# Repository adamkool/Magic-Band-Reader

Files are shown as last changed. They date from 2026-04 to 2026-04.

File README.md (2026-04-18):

# 🪄 Magic Band

Last Halloween I came across [this video](https://www.youtube.com/watch?v=f09JSgdGhIk) in a Facebook group with a replica of the Haunted Mansion Magic Band reader for the Lightning Lane at Disney World. Fortunately, the creator made the 3D print files available, but excluded the electronics that make it come to life. The electronics were excluded due to a complex, multi-unit custom implementation. Since my kids love going to Disney, I wanted to build one for them. There's also been growing interest in a standalone solution — so this is for everyone who would like to build their own.

mb-reader-static

## Overview

The Magic Band reader is powered by a Raspberry Pi Zero 2w. When powered on, the Raspberry Pi will automatically run the program. In the idle state, the LED lights will circle the reader. When an RFID card is presented to the reader, an LED animation is triggered along with a "chime" sound. If the audio is replaced with something longer, there is an option to tap the RFID card again which will stop the audio. The lights will briefly turn the lights red to acknowledge the tap.

The current implementation of this Magic Band reader is compatible with virtually any 13.56MHz RFID device.

## Bill of Materials

- **[Raspberry Pi Zero 2W](https://www.digikey.ca/en/products/detail/raspberry-pi/SC0721/24627135)** — The brains of the operation
- **[RC522 Mini RFID Reader](https://www.aliexpress.com/item/1005006907801802.html)** — SPI-connected tag scanning
- **[MAX98357A I2S Amplifier](https://www.digikey.ca/en/products/detail/adafruit-industries-llc/3006/6058477)** — digital audio output
- **[Adafruit 3351 Speaker](https://www.digikey.ca/en/products/detail/adafruit-industries-llc/3351/6612456)** - plays audio, does not require power source
- **[BTF-Lighting 1m 144 Light LED Strip](https://www.amazon.ca/dp/B0F5WQLMK7?ref_=ppx_hzsearch_conn_dt_b_fed_asin_title_6&th=1)** — LED lights
- **[BTF-Lighting 5V 6A PSU](https://www.amazon.ca/dp/B0FNWDR7TT?ref_=ppx_hzsearch_conn_dt_b_fed_asin_title_2&th=1)** — powers LED lights
- **[Micro SD card 32-64gb](https://www.amazon.ca/SanDisk-Extreme-microSDXC-Memory-Adapter/dp/B09X7C7LL1?th=1)** - SD card for Raspberry Pi OS and audio files
- **[Dupont cables](https://www.amazon.ca/RGBZONE-Multicolored-Breadboard-Arduino-Raspberry/dp/B08TWSV2DY?th=1)** - Various cables to connect everything
- **[WAGO 221 Lever Nuts](https://www.homedepot.ca/product/wago-lever-nuts-3-conductor-compact-splicing-connectors-12-24awg-10-pack-/1001877147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)** - Easily connect wires together without having to solder them

All of the materials needed to make the housing for the electronics can be found in the [Makerworld file](https://makerworld.com/en/models/1998101-disney-haunted-mansion-inspired-magicband-reader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)

## Features

- RFID tag detection triggers LED lights and audio file
- Programming of individual RFID tags is not needed. There is no limit on how many tags you can use.
- Replaceable audio with stop functionality
- Animation timing is easily configurable

## Tech Stack

- Python (Pi-side RFID + LED lights + audio logic)
- I2S audio, SPI (RFID)

## Supporting files

- [Model of the Magic Band reader housing](https://makerworld.com/en/models/1998101-disney-haunted-mansion-inspired-magicband-reader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)
- [Internal control panel (Print ready)](https://github.com/adamkool/magic-band-reader/blob/0c3ac6cd2602aba7beed5e0e5c9bfb62491abfb1/Magic%20Band%20Control%20Board.stl)
- [Internal control panel Fusion file (Excludes WAGO terminal)](https://github.com/adamkool/magic-band-reader/blob/0c3ac6cd2602aba7beed5e0e5c9bfb62491abfb1/Magic%20Band%20Control%20Board.f3d)
- [WAGO Terminal](https://makerworld.com/en/models/936345-wago-221-awg-24-12-connector-modular-mount-for-3x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)

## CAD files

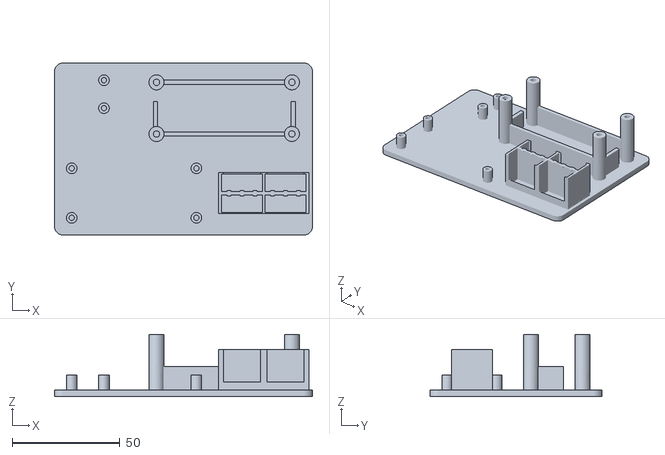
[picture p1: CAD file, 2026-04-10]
Magic Band Control Board.stl
120.0 x 80.0 x 29.0

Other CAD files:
Magic Band Control Board.f3d

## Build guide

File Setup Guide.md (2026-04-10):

# Magic Band RFID Audio Player — Complete Setup Guide

A beginner-friendly guide to building an RFID-triggered audio player with LED animations using a Raspberry Pi Zero 2W. When you tap an RFID tag, the LEDs animate and a chime plays — just like a Disney Magic Band.

---

## What You'll Need

### Hardware
| Item | Notes |
|---|---|
| Raspberry Pi Zero 2W | The main brain of the project |
| MicroSD card | 32GB, Class 10 minimum |
| RC522 RFID Reader Module | Reads your RFID tags |
| RFID Tags | 13.56MHz — at least 1 for testing |
| MAX98357A I2S Audio Amplifier | Plays the audio |
| Speaker | 4–8Ω, 3W |
| WS2812B LED Strip | Up to 144 pixels |
| 5V External Power Supply | 10A+ for 144 LEDs |
| Micro USB cable | Powers the Pi |
| Jumper wires | Female-to-female |

---

## Part 1 — Wiring

> ⚠️ **Always power off the Pi before changing wiring.**

### RFID Reader (RC522) → Pi

```
RC522 Pin    →    Pi Pin         (GPIO)
━━━━━━━━━━━━━━━━━━━━━━━━━━━━━━━━━━━━━━
SDA (SS)     →    Pin 24         (GPIO 8,  SPI CE0)
SCK          →    Pin 23         (GPIO 11, SPI CLK)
MOSI         →    Pin 19         (GPIO 10, SPI MOSI)
MISO         →    Pin 21         (GPIO 9,  SPI MISO)
RST          →    Pin 22         (GPIO 25)
3.3V         →    Pin 1          (3.3V)
GND          →    Pin 6          (GND)
```

### Audio Amplifier (MAX98357A) → Pi

```
MAX98357A    →    Pi Pin         (GPIO)
━━━━━━━━━━━━━━━━━━━━━━━━━━━━━━━━━━━━━━
VIN          →    Pin 2          (5V)
GND          →    Pin 14         (GND)
DIN          →    Pin 40         (GPIO 21, I2S Data)
BCLK         →    Pin 12         (GPIO 18, I2S Clock)
LRC          →    Pin 35         (GPIO 19, I2S LR)
GAIN         →    Pin 16         (GPIO 23)
```

### LED Strip → Pi + External Power Supply

```
LED Strip    →    Destination
━━━━━━━━━━━━━━━━━━━━━━━━━━━━━━━━━━━━━━
DIN (Data)   →    Pi Pin 32      (GPIO 12)
5V (Red)     →    External PSU +5V
GND (Black)  →    External PSU GND  ← also connect to Pi GND!
```

### Speaker → Audio Amplifier

```
Speaker      →    MAX98357A
━━━━━━━━━━━━━━━━━━━━━━━━━━━━━━━━━━━━━━
+ (positive) →    MAX98357A +
- (negative) →    MAX98357A -
```

---

### Complete Visual Wiring Diagram

```
Pi Zero 2W                          Components
══════════                          ══════════

[Pin  1 / 3.3V    ] ─────────────► RFID 3.3V
[Pin  6 / GND     ] ─────────────► RFID GND
[Pin 19 / GPIO 10 ] ─────────────► RFID MOSI
[Pin 21 / GPIO  9 ] ─────────────► RFID MISO
[Pin 22 / GPIO 25 ] ─────────────► RFID RST
[Pin 23 / GPIO 11 ] ─────────────► RFID SCK
[Pin 24 / GPIO  8 ] ─────────────► RFID SDA

[Pin  2 / 5V      ] ─────────────► Audio Amp VIN
[Pin 14 / GND     ] ─────────────► Audio Amp GND
[Pin 12 / GPIO 18 ] ─────────────► Audio Amp BCLK
[Pin 16 / GPIO 23 ] ─────────────► Audio Amp GAIN
[Pin 35 / GPIO 19 ] ─────────────► Audio Amp LRC
[Pin 40 / GPIO 21 ] ─────────────► Audio Amp DIN

[Pin 32 / GPIO 12 ] ─────────────► LED Strip DIN (data)

External PSU +5V ────────────────► LED Strip 5V  (red wire)
External PSU GND ────────┬───────► LED Strip GND (black wire)
                         └───────► Pi GND (Pin 6)  ← SHARED!

Audio Amp + ─────────────────────► Speaker +
Audio Amp - ─────────────────────► Speaker -
```

### Critical Wiring Rules

1. **Shared Ground** — Pi GND, LED power supply GND, and audio amp GND must all connect together
2. **LED Power** — Never power the LED strip from the Pi. Always use an external 5V supply
3. **LED Data Pin** — Use GPIO 12 (Pin 32), NOT GPIO 18 (that's used by audio)
4. **RFID RST Pin** — Must connect to GPIO 25 (Pin 22) for the reset sequence to work

---

### LED Daisy Chain (Two Strips)

If you have two LED strips, connect them in a chain:

```
Pi GPIO 12 ──────► Strip 1 DIN
                   Strip 1 DOUT ──────► Strip 2 DIN

External PSU +5V ──────┬──────────────► Strip 1 5V
                       └──────────────► Strip 2 5V

External PSU GND ──────┬──────────────► Strip 1 GND
                       ├──────────────► Strip 2 GND
                       └──────────────► Pi GND
```

> Power both strips directly from the PSU — don't chain power through Strip 1.

---

## Part 2 — Raspberry Pi OS Setup

### Step 1: Flash the SD Card

1. Download **Raspberry Pi Imager** from [raspberrypi.com/software](https://www.raspberrypi.com/software/)
2. Insert your MicroSD card
3. Open Imager → Choose OS → **Raspberry Pi OS Lite (64-bit)**
4. Click the gear icon ⚙️ and configure:
   - Set hostname: `Magic-Band`
   - Enable SSH
   - Set username: `admin`
   - Set a password
   - Configure your WiFi network
5. Click Write and wait for it to finish
6. Insert the SD card into the Pi and power it on

### Step 2: Connect via SSH

Wait about 60 seconds for the Pi to boot, then on your computer:

```bash
ssh admin@Magic-Band.local
```

Enter your password when prompted. If it doesn't connect, try:

```bash
ssh -v admin@Magic-Band.local
```

### Step 3: Enable SPI (Required for RFID)

```bash
sudo raspi-config
```

Navigate to: **Interface Options → SPI → Yes → Finish**

Then reboot:
```bash
sudo reboot
```

Reconnect via SSH after reboot, then verify SPI is enabled:
```bash
ls /dev/spi*
# Should show: /dev/spidev0.0  /dev/spidev0.1
```

### Step 4: Enable I2S Audio

```bash
sudo nano /boot/firmware/config.txt
```

Add these lines at the bottom:
```
dtparam=i2s=on
dtoverlay=i2s-mmap
dtoverlay=googlevoicehat-soundcard
```

Save with `Ctrl+X` → `Y` → `Enter`, then reboot:
```bash
sudo reboot
```

---

## Part 3 — Install Software

Reconnect via SSH, then run these commands one at a time:

### Step 1: Update the System

```bash
sudo apt update && sudo apt upgrade -y
```

### Step 2: Install Required Libraries

```bash
sudo pip3 install RPi.GPIO --break-system-packages
sudo pip3 install mfrc522 --break-system-packages
sudo pip3 install pygame --break-system-packages
sudo pip3 install rpi_ws281x --break-system-packages
sudo apt install -y ffmpeg
```

### Step 3: Create Project Folders

```bash
mkdir -p ~/magic-band/audio
```

### Step 4: Add Your Audio File

Copy your audio file to the Pi. From your computer (not the Pi):

```bash
scp /path/to/your/chime.wav admin@Magic-Band.local:~/magic-band/audio/
```

Then convert it to MP3 on the Pi:
```bash
ffmpeg -i ~/magic-band/audio/chime.wav ~/magic-band/audio/chime.mp3
```

---

## Part 4 — The Script

Create the main script:

```bash
nano ~/magic-band/magic_band.py
```

Paste the entire script below, then save with `Ctrl+X` → `Y` → `Enter`.

```python
#!/usr/bin/env python3
"""
Magic Band - Raspberry Pi Only
Controls RFID reader, audio playback, AND WS2812B LEDs directly.
No ESP32 required.

Run with: sudo python3 magic_band.py
"""

import RPi.GPIO as GPIO
import pygame
import time
import os
import threading
from rpi_ws281x import PixelStrip, Color

# ============= CONFIGURATION =============

# LED Configuration
LED_PIN        = 12       # GPIO 12 (Pin 32)
NUM_LEDS       = 42       # Total number of LEDs in your strip(s)
LED_BRIGHTNESS = 125      # 0-255 (125 = ~50%)
LED_FREQ_HZ    = 800000   # Signal frequency (800kHz for WS2812B)
LED_DMA        = 0        # 0 = PWM mode, avoids SPI/RFID conflict
LED_INVERT     = False
LED_CHANNEL    = 0

# Audio Configuration
AUDIO_FILE = "/home/admin/magic-band/audio/chime.mp3"

# Audio Amplifier GAIN Pin
GAIN_PIN = 23

# RFID
RST_PIN          = 25
COOLDOWN_SECONDS = 0.5

# Animation speeds (seconds)
IDLE_CHASE_DELAY       = 0.035  # Idle green chase speed (higher = slower)
TRIGGER_CHASE_DELAY    = 0.015  # Trigger chase speed (higher = slower)
TRIGGER_CHASE_DURATION = 1.0    # How long the trigger chase runs (seconds)
FLASH_ON_TIME          = 1.5    # How long solid green stays on (seconds)
FLASH_OFF_TIME         = 0.1    # Pause after flash before idle resumes

# ============= RFID SETUP =============

GPIO.setmode(GPIO.BCM)

# Hard reset MFRC522 via RST pin before importing library
GPIO.setup(RST_PIN, GPIO.OUT)
GPIO.output(RST_PIN, GPIO.LOW)   # Hold in reset
time.sleep(0.5)
GPIO.output(RST_PIN, GPIO.HIGH)  # Release reset
time.sleep(1.0)                  # Let it stabilize

from mfrc522 import SimpleMFRC522
reader = SimpleMFRC522()
print("✓ RFID reader initialized")

# ============= LED SETUP =============

strip = PixelStrip(
    NUM_LEDS, LED_PIN, LED_FREQ_HZ, LED_DMA,
    LED_INVERT, LED_BRIGHTNESS, LED_CHANNEL
)
strip.begin()
print("✓ LED strip initialized")

# ============= GPIO / AUDIO SETUP =============

GPIO.setup(GAIN_PIN, GPIO.OUT)
gain_pwm = GPIO.PWM(GAIN_PIN, 100)
gain_pwm.start(100)  # Max gain
print("✓ Audio gain configured")

os.environ['SDL_AUDIODRIVER'] = 'alsa'
os.environ['AUDIODEV'] = 'hw:0,0'

# Retry audio init until device is free
for attempt in range(10):
    try:
        pygame.mixer.init(frequency=22050, size=-16, channels=2, buffer=512)
        print("✓ Audio system initialized")
        break
    except pygame.error as e:
        print(f"⚠ Audio not ready (attempt {attempt+1}/10), retrying...")
        time.sleep(2)
else:
    print("✗ Audio device never became available")
    GPIO.cleanup()
    exit(1)

# ============= LED STATE =============

led_state = "IDLE"
led_lock  = threading.Lock()
chase_position_shared = 0

# ============= LED ANIMATION FUNCTIONS =============

def clear_strip():
    for i in range(NUM_LEDS):
        strip.setPixelColor(i, Color(0, 0, 0))
    strip.show()

def red_flash():
    """Flash all LEDs red for 1.0 seconds."""
    for i in range(NUM_LEDS):
        strip.setPixelColor(i, Color(255, 0, 0))
    strip.show()
    time.sleep(1.0)
    clear_strip()
    time.sleep(0.1)

def green_chase_frame(position):
    """Draw one frame of the idle green chase animation."""
    TAIL_LENGTH = 15
    for i in range(NUM_LEDS):
        strip.setPixelColor(i, Color(0, 0, 0))
    for i in range(TAIL_LENGTH):
        pos = (position + i) % NUM_LEDS
        brightness = int(255 * (TAIL_LENGTH - i) / TAIL_LENGTH)
        strip.setPixelColor(pos, Color(0, brightness, 0))
    strip.show()

def trigger_animation(start_pos):
    print("💡 Running trigger animation...")

    pos = start_pos
    chase_end = time.time() + TRIGGER_CHASE_DURATION
    while time.time() < chase_end:
        for i in range(NUM_LEDS):
            strip.setPixelColor(i, Color(0, 0, 0))
        for i in range(15):
            pixel = (pos - i) % NUM_LEDS
            brightness = min(255, int(255 * (15 - i) / 15))
            strip.setPixelColor(pixel, Color(0, brightness, 0))
        strip.show()
        pos = (pos + 1) % NUM_LEDS
        time.sleep(TRIGGER_CHASE_DELAY)

    # Flash green
    for i in range(NUM_LEDS):
        strip.setPixelColor(i, Color(0, 255, 0))
    strip.show()
    time.sleep(FLASH_ON_TIME)

    clear_strip()
    time.sleep(FLASH_OFF_TIME)

    print("✓ Trigger animation complete")

# ============= LED THREAD =============

def led_loop():
    global chase_position_shared
    chase_position = 0
    while True:
        with led_lock:
            state = led_state
            chase_position_shared = chase_position

        if state == "IDLE":
            green_chase_frame(chase_position)
            chase_position = (chase_position + 1) % NUM_LEDS
            time.sleep(IDLE_CHASE_DELAY)
        elif state == "TRIGGER":
            time.sleep(0.05)
        else:
            clear_strip()
            time.sleep(0.1)

led_thread = threading.Thread(target=led_loop, daemon=True)
led_thread.start()
print("✓ LED animation thread started")

# ============= TRIGGER SEQUENCE =============

def run_trigger_sequence():
    global led_state

    if pygame.mixer.music.get_busy():
        pygame.mixer.music.stop()
        time.sleep(0.1)
    pygame.mixer.music.load(AUDIO_FILE)
    pygame.mixer.music.play()
    pygame.mixer.music.set_volume(0.3)
    print("▶️  Playing audio...")

    with led_lock:
        start_pos = (chase_position_shared + 15) % NUM_LEDS
        led_state = "TRIGGER"
    time.sleep(0.06)

    trigger_animation(start_pos)

    with led_lock:
        led_state = "IDLE"

def stop_and_reset():
    """Stop audio, flash red, then reset LEDs to idle green chase."""
    global led_state
    print("⏹️  Stopping and resetting...")
    pygame.mixer.music.stop()
    with led_lock:
        led_state = "TRIGGER"
    red_flash()
    with led_lock:
        led_state = "IDLE"
    print("✓ Reset complete\n")

# ============= STARTUP CHECK =============

if not os.path.exists(AUDIO_FILE):
    print(f"✗ Audio file not found: {AUDIO_FILE}")
    print("Please upload an audio file to ~/magic-band/audio/")
    GPIO.cleanup()
    exit(1)
print(f"✓ Audio file ready: {os.path.basename(AUDIO_FILE)}")

print("\n" + "="*60)
print("🎵✨ MAGIC BAND READY!")
print("="*60)
print(f"RFID:  Waiting for tags...")
print(f"Audio: {os.path.basename(AUDIO_FILE)}")
print(f"LEDs:  Green chase running on GPIO {LED_PIN} ({NUM_LEDS} pixels)")
print("\nTap RFID tag to trigger!\n")

# ============= MAIN LOOP =============

last_tag_id    = None
last_read_time = 0

try:
    while True:
        id, text = reader.read()
        current_time = time.time()

        if id != last_tag_id or (current_time - last_read_time) > COOLDOWN_SECONDS:
            print("\n" + "─"*60)
            print(f"✨ RFID TAG DETECTED: {id}")
            print("─"*60)

            if pygame.mixer.music.get_busy():
                stop_and_reset()
            else:
                run_trigger_sequence()

            last_tag_id    = id
            last_read_time = current_time

except KeyboardInterrupt:
    print("\n\nShutting down Magic Band...")

finally:
    with led_lock:
        led_state = "OFF"
    time.sleep(0.1)
    clear_strip()

    pygame.mixer.music.stop()
    pygame.mixer.quit()

    gain_pwm.stop()
    GPIO.cleanup()
    print("✓ Cleanup complete. Goodbye!")
```

---

## Part 5 — Testing

### Test 1: LEDs Only

```bash
sudo python3 -c "
from rpi_ws281x import PixelStrip, Color
import time
strip = PixelStrip(42, 12, 800000, 0, False, 125, 0)
strip.begin()
print('Turning strip green for 3 seconds...')
for i in range(strip.numPixels()):
    strip.setPixelColor(i, Color(0, 255, 0))
strip.show()
time.sleep(3)
for i in range(strip.numPixels()):
    strip.setPixelColor(i, Color(0, 0, 0))
strip.show()
print('Done!')
"
```

### Test 2: RFID Reader Only

```bash
sudo python3 -c "
from mfrc522 import SimpleMFRC522
reader = SimpleMFRC522()
print('Tap your RFID tag now...')
id, text = reader.read()
print(f'Tag ID: {id}')
"
```

### Test 3: Full System

```bash
sudo python3 ~/magic-band/magic_band.py
```

Expected startup output:
```
✓ RFID reader initialized
✓ LED strip initialized
✓ Audio gain configured
✓ Audio system initialized
✓ LED animation thread started
✓ Audio file ready: chime.mp3

============================================================
🎵✨ MAGIC BAND READY!
============================================================
Tap RFID tag to trigger!
```

---

## Part 6 — Auto-Start on Boot

### Step 1: Create the Service File

```bash
sudo nano /etc/systemd/system/magic-band.service
```

Paste:
```ini
[Unit]
Description=Magic Band RFID Audio Player
After=sound.target

[Service]
Type=simple
User=root
WorkingDirectory=/home/admin/magic-band
ExecStart=/usr/bin/python3 /home/admin/magic-band/magic_band.py
Restart=always
RestartSec=10

[Install]
WantedBy=multi-user.target
```

### Step 2: Enable and Start

```bash
sudo systemctl daemon-reload
sudo systemctl enable magic-band.service
sudo systemctl start magic-band.service
```

### Step 3: Test Boot

```bash
sudo reboot
```

After 60 seconds the LEDs should start animating automatically. Tap your RFID tag to trigger the full sequence.

---

## Part 7 — Adjusting Settings

All timing and brightness settings are at the top of `magic_band.py`:

| Setting | Default | What It Does |
|---|---|---|
| `NUM_LEDS` | 42 | Total number of LEDs |
| `LED_BRIGHTNESS` | 125 | LED brightness (0-255) |
| `IDLE_CHASE_DELAY` | 0.035 | Idle chase speed (higher = slower) |
| `TRIGGER_CHASE_DELAY` | 0.015 | Trigger chase speed (higher = slower) |
| `TRIGGER_CHASE_DURATION` | 1.0 | How long the fast chase runs (seconds) |
| `FLASH_ON_TIME` | 1.5 | How long the green flash stays on (seconds) |
| `AUDIO_FILE` | chime.mp3 | Path to your audio file |

To edit:
```bash
# Stop the service first
sudo systemctl stop magic-band.service

# Edit the script
nano ~/magic-band/magic_band.py

# Test your changes
sudo python3 ~/magic-band/magic_band.py

# When happy, restart the service
sudo systemctl start magic-band.service
```

---

## Part 8 — How It Works

### Tap Sequence
1. **Tap RFID tag** → audio plays immediately
2. **LEDs speed up** into fast chase animation
3. **Green flash** at end of chase
4. **LEDs return** to slow idle chase
5. **Tap again while audio plays** → red flash, audio stops, back to idle

### Why These Specific Pins?
- **GPIO 12** for LEDs — uses PWM0, avoids conflicting with SPI (used by RFID)
- **GPIO 18** for audio clock — standard I2S pin
- **GPIO 25** for RFID reset — used to hard-reset the reader on boot

### The RST Pin Fix
The RFID reader can hang during boot if initialized too early. The script manually pulls the RST pin LOW then HIGH before initializing the reader, forcing a clean hardware reset every time.

---

## Troubleshooting

### LEDs don't light up
- Run the LED test above
- Check GPIO 12 → LED DIN connection
- Verify external power supply is on
- Confirm shared ground between Pi and PSU

### RFID not reading
- Check SPI is enabled: `ls /dev/spi*` should show `/dev/spidev0.0`
- Verify all 7 RFID wires are connected
- Run the isolated RFID test above

### No audio
- Check speaker wires to MAX98357A
- Verify VIN on MAX98357A goes to 5V (not 3.3V)
- Check I2S overlay is in `/boot/firmware/config.txt`
- Run: `aplay -l` to list audio devices

### Service won't start
```bash
sudo journalctl -u magic-band.service -f
```
This shows live logs — paste any errors for diagnosis.

### SSH won't connect
```bash
ssh -v admin@Magic-Band.local
```
The `-v` flag shows verbose output to diagnose connection issues.

---

## Quick Reference Commands

```bash
# Run script manually (stop service first)
sudo systemctl stop magic-band.service
sudo python3 ~/magic-band/magic_band.py

# Service management
sudo systemctl start magic-band.service
sudo systemctl stop magic-band.service
sudo systemctl restart magic-band.service
sudo systemctl status magic-band.service

# View live service logs
sudo journalctl -u magic-band.service -f

# Convert audio file
ffmpeg -i ~/magic-band/audio/input.wav ~/magic-band/audio/output.mp3

# Force kill service if stuck
sudo systemctl kill magic-band.service
```

---

## Bill of Materials

| Item | Approximate Cost |
|---|---|
| Raspberry Pi Zero 2W | $15 |
| MicroSD Card 32GB | $8 |
| RC522 RFID Reader + Tags | $8 |
| MAX98357A Audio Amp | $6 |
| WS2812B LED Strip (1m/144px) | $12 |
| Speaker (3W 8Ω) | $5 |
| 5V 10A Power Supply | $15 |
| Jumper Wires | $5 |
| **Total** | **~$74** |

---

*Version 2.0 — Pi Only Edition — April 2026*
